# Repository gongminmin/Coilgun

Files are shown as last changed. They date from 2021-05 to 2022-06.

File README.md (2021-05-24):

# Coilgun



A coilgun is a type of mass driver. It contains one or more electromagnets to accelerate a ferromagnetic projectile to a high velocity. This project is a design of a toy level multi-stage coilgun. We'd like to make it easy to implement, so people can build it as a hobby project.

NOTE: Please turn on git LFS when cloning this project.

## Design

The principle of our design, and a detailed introduction of subsystems are in [Design](Doc/Design.md)

## Disclaimer

A coilgun is operated by **LETHALLY** high voltage and current. If you don't have enough knowledge and experiences on high voltage electric, please keep extreme cautions on insulation.

## Directories

* Circuit folder is the electric design of the system. The files can be open by [KiCad](https://kicad-pcb.org/)
* Doc folder contains some documents

## License

Coilgun is distributed under the terms of MIT License. See [LICENSE](LICENSE) for details.

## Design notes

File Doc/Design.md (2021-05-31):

# Design

The basic idea of coilgun can be found at [wikipedia](https://en.wikipedia.org/wiki/Coilgun). Here we implement a 3-stage coilgun. More stages can accelerate the projectile to a higher velocity.

Subsystems

## Operation Cycle

The propulsion system is running in cycles. Each cycle takes steps below.

1. The power starts charging capacitors in coil stages,
1. Push the manual trigger of stage 1
1. The capacitor in stage 1 is discharged
1. The coil in stage 1 generates a magnet field
1. The projectile gets accelerated by the magnet field towards stage 2
1. The projectile reaches the middie of the coil, the capacitor stops discharging
1. The projectile keeps moving in inertia
1. The projectile cuts off the light in auto trigger of stage 2
1. The capacitor in stage 2 is discharged
1. The coil in stage 2 generates a magnet field
1. The projectile get accelerated by the magnet field towards stage 3
...

It'll keep going until the projectile goes through all stages.

## Subsystems

The system is composed of several subsystems.

### Power

The power subsystem converts 12V DC to 450V DC for charging capacitors.

See also [Power Subsystem](PowerSubsystem.md)

### Coil Stage

When triggered, the capacitor in a stage discharge the energy to the coil in a very short time peroid.

See also [Coil Stage Subsystem](CoilStageSubsystem.md)

### Sensor

The sensor subsystem is optional. It tells the user the charging status of capacitors.

See also [Sensor Subsystem](SensorSubsystem.md)

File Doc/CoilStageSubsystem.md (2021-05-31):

# Coil Stage Subsystem

## Trigger

There are 2 types of triggers can be used, manual one and auto one. The manual one is connected to the first stage. An user can push a button to trigger it. It's simply a switch.

Manual Trigger Circuit

The auto trigger contains an infrared LED and a phototransistor. The LED is always on, making the phototransistor normally on, trigger signal is in low level. When a projectile gets between the LED and the phototransistor, it blocks the light. The phototransistor is turned off, sending a high level signal out. The auto trigger is used in stages other that first stage.

Auto Trigger Circuit

## Capacitor and Coil

The capacitor is charged to 450V by power subsystem. A SCR controls the discharge. When it's triggered, the energy is transfered from capacitor to coil, generates a strong magnet field.

Coil Stage Circuit

The coil needs to be energized in a very short time, and disengaged right after the projectile pass through the middle of the coil. So we need a power source that provides high voltage and high current as a pulse. For doing this, high voltage capacitor is a much lighter and more efficient than put a bunch of batteries in serial for high voltage and in parallel for high current.

We choose SCRs here as a solid state switch. Compare to power MOSFETs, SCRs are good at handling high voltage and high current, with a lower frequency switching. These properties are exactly what we want. However, A SCR can't be turnned of by set a low leve signal to their gates. it keeps on until there is no potential difference between its anode and cathode. That means once triggered, the C1 discharges until it's empty. We have no control on discharge time.

## Connection

The interface of triggers are the same. This design makes the capacitor and coil module exchangeable. Connect it different types of triggers can change it to the first stages or the rest stages.

**CAUSION**: Don't touch any metal part before capacitor finish discharging. The voltage and current are lethal.

## Calculations

The energy stores in one capacitor is:

`J = 0.5 * C * V * V = 0.5 * 0.00033 * 450 * 450 = 33.41 J`

The coil is about 5Ω, makes the discharge time:

`s = C * R = 0.00033 * 5 = 1.65 ms`

And the maximum discharge current:

`A = V / R = 450 / 5 = 90 A`

## Future improvements

As we mentioned before, the current to the coil must be cut off when the projectile reaches the middle of the coil. Any delay makes the projectile slow down or move backwards. That means we need a precious discharge timing control. When the number of stages goes higher, it become a more serious problem. Because the projectile is accelerating, the discharge times are different in stages. As a result, we may need to use power MOSFETs or IGBTs as switches, and use microcontrollers to control the timing. Multiple experiments are requires to adjust the best timing of each stage.

[TODO: Discussion about iron core]

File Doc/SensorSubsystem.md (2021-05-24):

# Sensor Subsystem

This is an optional subsystem. It doesn't provide the key functionality to the coilgun. Since capacitors may need seconds to finish charging, this subsystem helps user to know the status.

Sensor Subsystem

## Adapter

The adapter here is a linear divider. It takes an input voltage, divide it with a constant value, and send the result to voltage sensor. By using different values of resistors, we can adapt the same voltage sensor to different input voltages.

Sensor Adapter Circuit

## Voltage Sensor

The next part is a voltage sensor circuit. It takes a low voltage signal from adapter, compare it with reference voltages. During the charging, LEDs will be lit up one by one. If the capacitor is full, the 4th LED is on.

Voltage Sensor Circuit

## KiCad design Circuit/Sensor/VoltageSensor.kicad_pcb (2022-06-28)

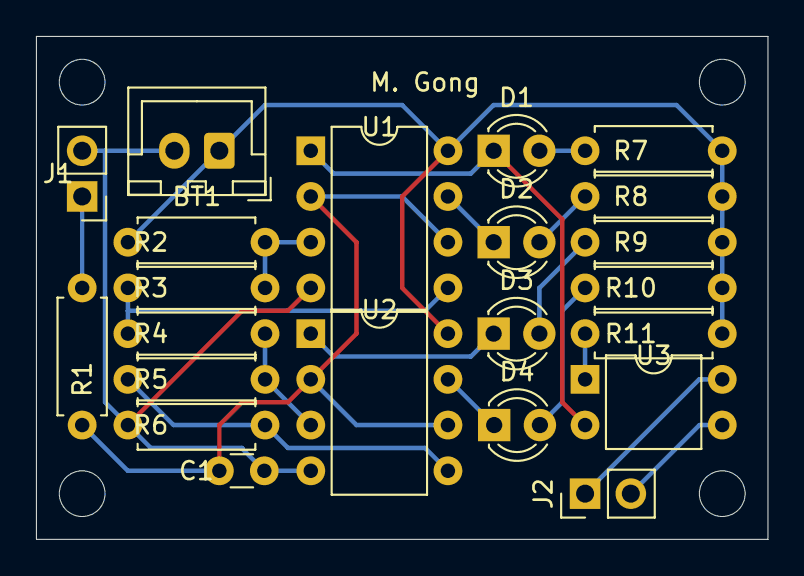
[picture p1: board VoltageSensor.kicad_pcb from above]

Board: 2 copper layers, 40.6 x 27.9 mm, 22 parts (0 on the bottom side), 19 nets.

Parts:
BT1: 12V Battery; JST_XH_B2B-XH-A_1x02_P2.50mm_Vertical
C1: 0.1uF; C_Disc_D3.0mm_W1.6mm_P2.50mm
D1, D2, D3, D4: LED; LED_D3.0mm_FlatTop
J1: From Capacitor Bank; PinHeader_1x02_P2.54mm_Vertical
J2: To Control; PinHeader_1x02_P2.54mm_Vertical
R1, R11: 1K; R_Axial_DIN0207_L6.3mm_D2.5mm_P7.62mm_Horizontal
R2: 20K; R_Axial_DIN0207_L6.3mm_D2.5mm_P7.62mm_Horizontal
R3, R4, R5, R6: 4.7K; R_Axial_DIN0207_L6.3mm_D2.5mm_P7.62mm_Horizontal
R7, R8, R9, R10: 2.2K; R_Axial_DIN0207_L6.3mm_D2.5mm_P7.62mm_Horizontal
U1, U2: LM393; DIP-8_W7.62mm
U3: PC817; DIP-4_W7.62mm

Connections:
+12V: BT1.1, R2.2, R7.1, R8.1, R9.1, R10.1, R11.1, U1.8, U2.8
/ControlGND: J2.2, U3.3
/ControlSignal: J2.1, U3.4
/Sensor6V: J1.1, R1.2
GND: BT1.2, C1.2, J1.2, R6.1, U1.4, U2.4
unnamed: C1.1, R1.1, U1.2, U1.6, U2.2, U2.6
unnamed: D1.1, U1.1, U3.2
unnamed: D1.2, R7.2
unnamed: D2.1, U1.7
unnamed: D2.2, R8.2
unnamed: D3.1, U2.1
unnamed: D3.2, R9.2
unnamed: D4.1, U2.7
unnamed: D4.2, R10.2
unnamed: R2.1, R3.2, U1.3
unnamed: R3.1, R4.2, U1.5
unnamed: R4.1, R5.2, U2.3
unnamed: R5.1, R6.2, U2.5
unnamed: R11.2, U3.1

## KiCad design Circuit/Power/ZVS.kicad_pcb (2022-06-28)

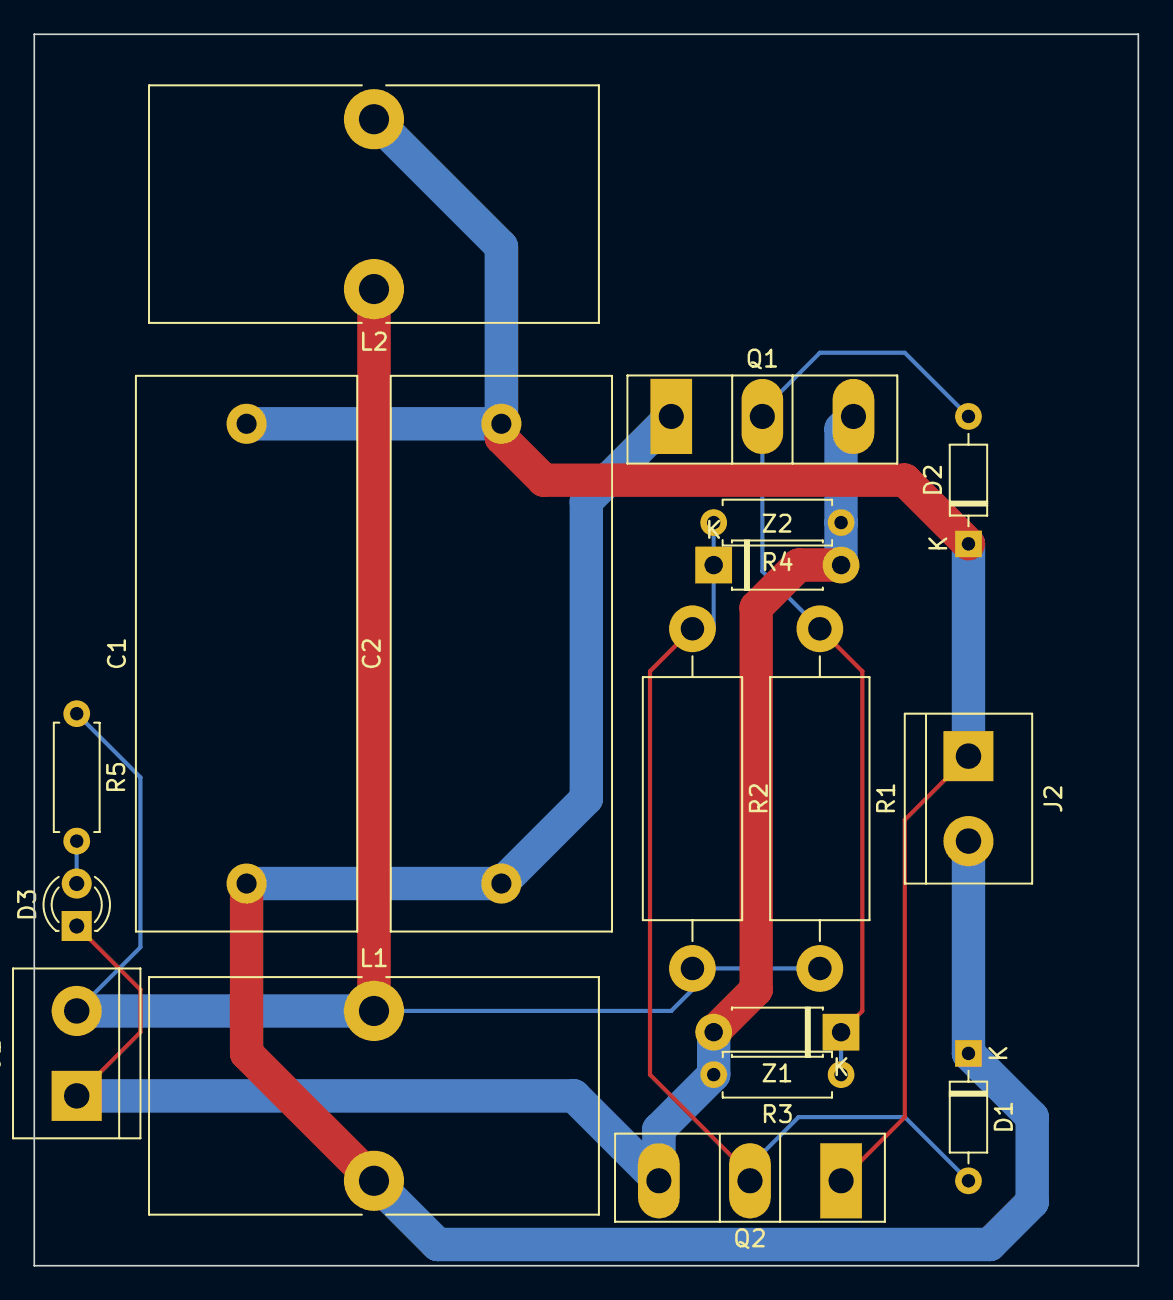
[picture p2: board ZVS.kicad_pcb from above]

Board: 2 copper layers, 66.0 x 73.7 mm, 18 parts (0 on the bottom side), 7 nets.

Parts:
C1, C2: MKP 0.33uF; C_Rect_L33.0mm_W13.0mm_P27.50mm_MKS4
D1, D2: FR107; D_DO-35_SOD27_P7.62mm_Horizontal
D3: LED; LED_D3.0mm_FlatTop
J1: 12V DC in; TerminalBlock_bornier-2_P5.08mm
J2: Output; TerminalBlock_bornier-2_P5.08mm
L1, L2: 100uH; L_Toroid_Vertical_L26.7mm_W14.0mm_P10.16mm_Pulse_D
Q1, Q2: IRFP250; TO-247-3_Vertical
R1, R2: 470 2W; R_Axial_DIN0614_L14.3mm_D5.7mm_P20.32mm_Horizontal
R3, R4: 10K; R_Axial_DIN0207_L6.3mm_D2.5mm_P7.62mm_Horizontal
R5: 2.2K; R_Axial_DIN0207_L6.3mm_D2.5mm_P7.62mm_Horizontal
Z1, Z2: 1N4742; D_DO-41_SOD81_P7.62mm_Horizontal

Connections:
/DCInput+: J1.2, L1.1, L2.1, R1.2, R2.2, R5.1
/DCInput-: D3.1, J1.1, Q1.3, Q2.3, R3.2, R4.1, Z1.2, Z2.2
/Output+: C1.1, C2.1, D1.1, J2.2, L1.2, Q1.1
/Output-: C1.2, C2.2, D2.1, J2.1, L2.2, Q2.1
unnamed: D1.2, Q2.2, R2.1, R4.2, Z2.1
unnamed: D2.2, Q1.2, R1.1, R3.1, Z1.1
unnamed: D3.2, R5.2

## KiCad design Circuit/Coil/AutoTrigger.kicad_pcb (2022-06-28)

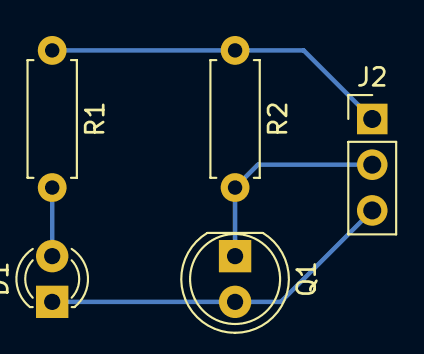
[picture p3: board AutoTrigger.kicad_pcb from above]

Board: 2 copper layers, 5 parts (0 on the bottom side), 4 nets.

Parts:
D1: LED; LED_D3.0mm_FlatTop
J2: Trigger; PinHeader_1x03_P2.54mm_Vertical
Q1: BP103B; LED_D5.0mm_Clear
R1, R2: 2.2K; R_Axial_DIN0207_L6.3mm_D2.5mm_P7.62mm_Horizontal

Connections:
/Trigger+: J2.1, R1.1, R2.1
/TriggerSignal: J2.2, Q1.1, R2.2
GND: D1.1, J2.3, Q1.2
unnamed: D1.2, R1.2

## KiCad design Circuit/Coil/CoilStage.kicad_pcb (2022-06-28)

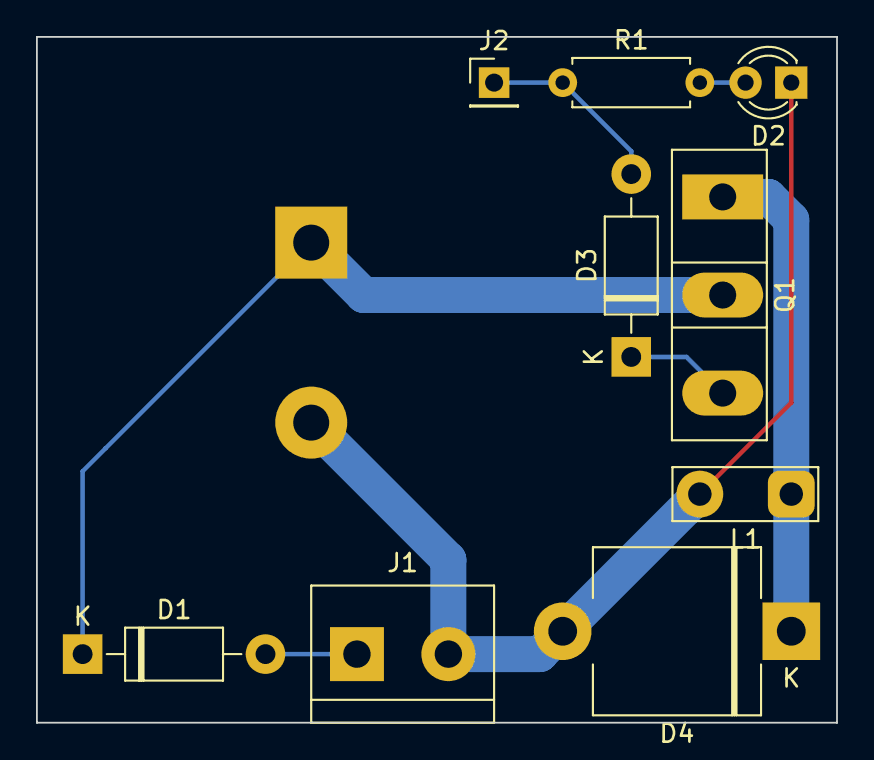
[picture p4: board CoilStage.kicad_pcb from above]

Board: 2 copper layers, 44.4 x 38.1 mm, 10 parts (1 on the bottom side), 7 nets.

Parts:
C1: 330uF 450V; CP_Radial_D30.0mm_P10.00mm_SnapIn
D1, D3: 1N4007; D_DO-41_SOD81_P10.16mm_Horizontal
D2: LED; LED_D3.0mm_FlatTop
D4: P1000M; D_P600_R-6_P12.70mm_Horizontal
J1: Coil Power; TerminalBlock_bornier-2_P5.08mm
J2: Trigger; PinHeader_1x01_P2.54mm_Vertical
L1: Electromagnetic; TestPoint_2Pads_Pitch5.08mm_Drill1.3mm
Q1: 70PT12DS; TO-247-3_Vertical
R1: 2.2K; R_Axial_DIN0207_L6.3mm_D2.5mm_P7.62mm_Horizontal

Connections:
/CoilPower+: D1.2, J1.1
/TriggerSignal: D3.2, J2.1, R1.1
GND: C1.2, D2.1, D4.2, J1.2, L1.2
unnamed: C1.1, D1.1, Q1.2
unnamed: D2.2, R1.2
unnamed: D3.1, Q1.3
unnamed: D4.1, L1.1, Q1.1

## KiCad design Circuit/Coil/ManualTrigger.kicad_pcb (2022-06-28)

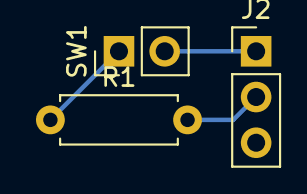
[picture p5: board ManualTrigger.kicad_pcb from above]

Board: 2 copper layers, 3 parts (0 on the bottom side), 3 nets.

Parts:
J2: Trigger; PinHeader_1x03_P2.54mm_Vertical
R1: 2.2K; R_Axial_DIN0207_L6.3mm_D2.5mm_P7.62mm_Horizontal
SW1: SW_Push; PinHeader_1x02_P2.54mm_Vertical

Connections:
/Trigger+: J2.1, SW1.2
/TriggerSignal: J2.2, R1.2
unnamed: R1.1, SW1.1

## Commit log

2021-05-24 Init commit
    [AutoTrigger.sch, CoilGun.sch, CoilStage.sch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]
2021-05-31 [Circuit] Add PCB design
    [AutoTrigger.kicad_pcb, AutoTrigger.sch, CoilStage.kicad_pcb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]
2021-05-31 [Circuit] File clean
    [Coilgun.sch]
2021-06-01 [Circuit] Optimize a PCB design
    [CoilStage.kicad_pcb]
2021-06-03 [Circuit] Use a bigger SCR
    [CoilStage.kicad_pcb, CoilStage.sch]
2021-06-05 [Doc] Update the circuit image
2022-06-28 [Circuit] Update circuit files to KiCAD 6's
    [AutoTrigger.kicad_pcb, AutoTrigger.kicad_sch, AutoTrigger.sch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]
